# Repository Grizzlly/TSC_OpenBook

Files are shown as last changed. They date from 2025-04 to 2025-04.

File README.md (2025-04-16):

# OpenBook

An open source e-book reader based on ESP32.

## Block diagram

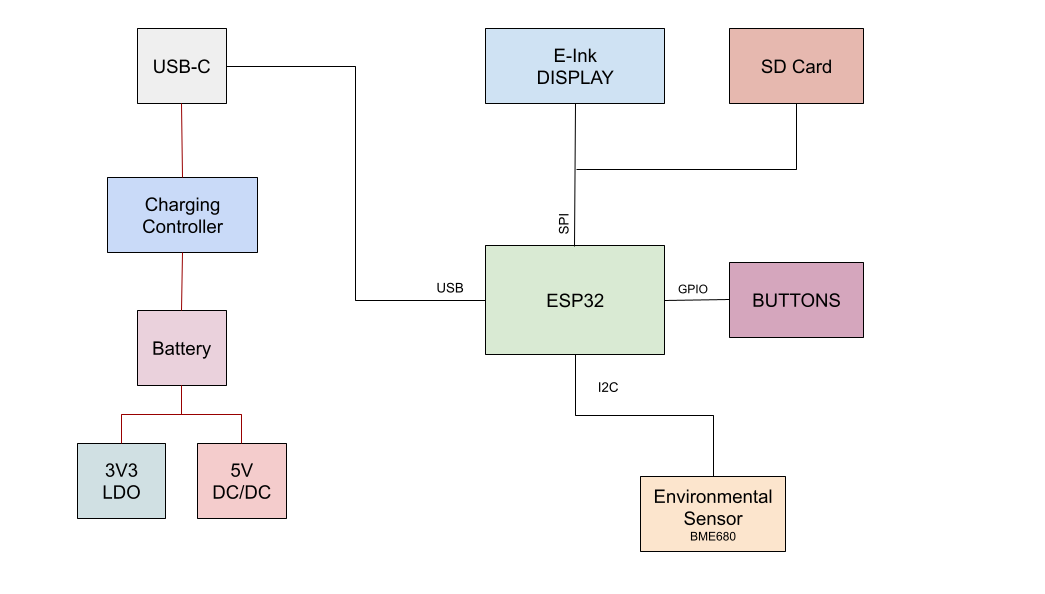
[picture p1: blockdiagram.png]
Block Diagram


## Hardware features

The main component of the device is the `ESP32` microcontroller, which is responsible for all the processing and control of the device. The `ESP32` is a powerful microcontroller with built-in Wi-Fi and Bluetooth capabilities, making it ideal for IoT applications.

Apart from the microcontroller, we have:

- `E-Paper Display`: connected via SPI interface.
- `SD Card`: connected via SPI interface.
- `USB-C charging and protection`: connected to the battery and the microcontroller. It also has electro static discharge protection.
- `Environmental sensors`: connected via I2C interface. These sensors measure temperature, humidity, and pressure.

## Power consumption

The `ESP32` microcontroller consumes `~250 mA` when
in use.
The display uses `~15 mA` when active.
The environmental sensors use `~3 mA` when active.

In total when active, the device consumes `~270 mA`. Given
that the battery has a capacity of `1800 mAh`,
we should expect a battery life of `~6.5 hours` of continuous use.

## Pin mapping for the ESP32

| Pin Name | Description | 
| --- | --- |
| EN | Reset |
| IO0 | Interrupt RTC |
| IO1 | Oscilator RTC |
| IO2 | SPI MISO |
| IO3 | Status display |
| IO4 | SD Card |
| IO5 | Data/Command |
| IO6 | SPI clock |
| IO7 | SPI data out |
| IO9 | Boot |
| IO10 | SPI E-Paper display command |
| IO11 | EPD |
| IO12 | Flash |
| IO13 | USB Data - |
| IO14 | USB Data + |
| IO15 | Navigation |
| IO16 | TX |
| IO17 | RX |
| IO18 | Reset DS3231 |
| IO19 | I2C Power |
| IO20 | EPD Power |
| IO21 | BME688 |
| IO22 | BME688 |
| IO23 | Reset display |

## BOM

| Piece Name | Quantity | Link |
| --- | --- | --- |
| ADAFRUIT_LEDCHIP-LED0603 | 1 | https://www.snapeda.com/parts/KP-1608SURCK/Kingbright/view-part/?ref=search&t=LED%200603 |
| C0402 | 1 | https://componentsearchengine.com/part-view/CC0402MRX5R5BB106/YAGEO |
| 112ATAARR03 | 1 | https://www.snapeda.com/parts/112A-TAAR-R03/Attend/view-part/ |
| 744043680 | 1 | https://eu.mouser.com/ProductDetail/Wurth-Elektronik/744043680?qs=PGXP4M47uW6VkZq%252BkzjrHA%3D%3D |
| BD5229G-TR | 1 | https://www.snapeda.com/parts/BD5229G-TR/Rohm/view-part/?ref=search&t=BD5229G-TR |
| CPH3225A | 1 | https://www.snapeda.com/parts/CPH3225A/Seiko/view-part/ |
| BUTTON_CUSYOMV1 | 3 | https://www.snapeda.com/search/?q=EVQP7L01P&search-type=parts |
| DS3231SN | 1 | https://www.snapeda.com/parts/DS3231SN%23/Analog%20Devices/view-part/?ref=search&t=DS3231SN%23 |
| ESP32 | 1 | https://www.snapeda.com/parts/ESP32-C6-WROOM-1-N8/Espressif%20Systems/view-part/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 |
| VARISTOR | 1 | https://ro.mouser.com/ProductDetail/EPCOS-TDK/B72520T0350K062?qs=dEfas%2FXlABIszF52uu7vrg%3D%3D |
| SD0805S020S1R0 | 1 | https://componentsearchengine.com/part-view/SD0805S020S1R0/Kyocera%20AVX |
| BME680 | 1 | https://www.snapeda.com/parts/BME680/Bosch%20Sensortec/view-part/?ref=search&t=bme680 |
| R0402 | 1 | https://componentsearchengine.com/part-view/R0402%201%25%20100%20K%20(RC0402FR-07100KL)/YAGEO |
| MOSFET | 1 | https://componentsearchengine.com/part-view/DMG2305UX-7/Diodes%20Incorporated |
| MCP73831 | 1 | https://componentsearchengine.com/part-view/MCP73831T-2ACI%2FOT/Microchip |
| SRJ | 1 | https://componentsearchengine.com/part-view/FH34SRJ-24S-0.5SH(99)/Hirose |
| MBR0530 | 1 | https://www.snapeda.com/parts/MBR0530/Onsemi/view-part/ |
| PGB1010603MR | 1 | https://www.snapeda.com/parts/PGB1010603MR/Littelfuse/view-part/ |
| QWIIC_CONNECTOR | 1 | https://www.snapeda.com/parts/PRT-14417/SparkFun/view-part/ |
| RCL_CPOL-EU | 1 | https://grabcad.com/library/tantalum-smd-capacitor-type-b-3528-1 |
| SAMACSYS_PARTS_USB4110-GF-A | 1 | https://www.snapeda.com/parts/USB4110-GF-A./Global%20Connector%20Technology/view-part/ |
| SI1308EDL-T1-GE3 | 1 | https://www.snapeda.com/parts/SI1308EDL-T1-GE3/Vishay/view-part/ |
| USBLC6-2SC6Y | 1 | https://www.snapeda.com/parts/USBLC6-2SC6Y/STMicroelectronics/view-part/?ref=dk&t=USBLC6-2SC6Y&con_ref=None |
| W25Q512JVEIQ | 1 | https://www.snapeda.com/parts/W25Q512JVEIQ/Winbond%20Electronics/view-part/?ref=search&t=W25Q512JVEIQ |
| XC6220A331MR-G | 1 | https://ro.mouser.com/ProductDetail/Torex-Semiconductor/XC6220A331MR-G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 |

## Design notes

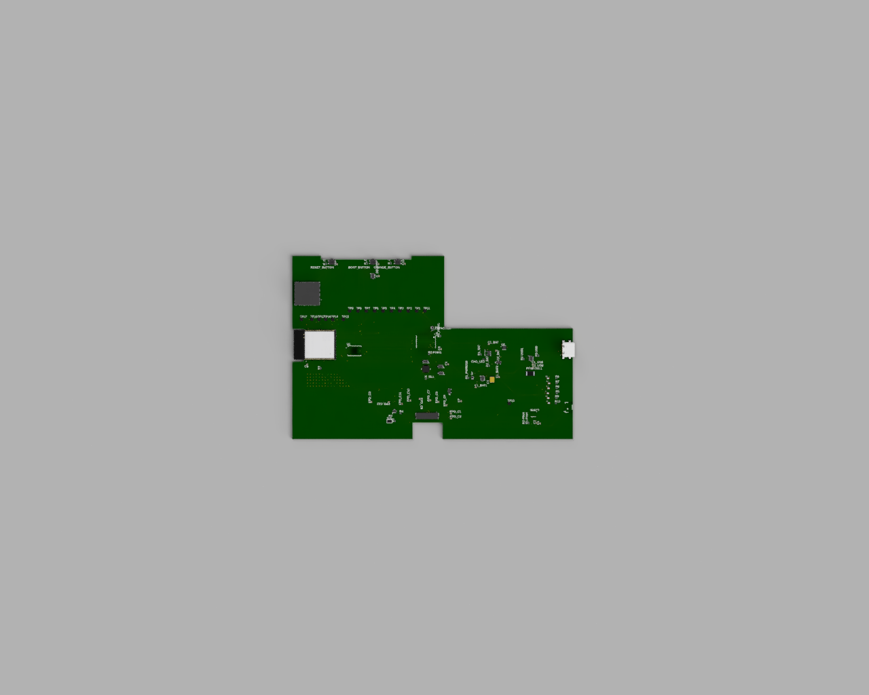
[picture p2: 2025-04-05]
Images/pcb_top.png

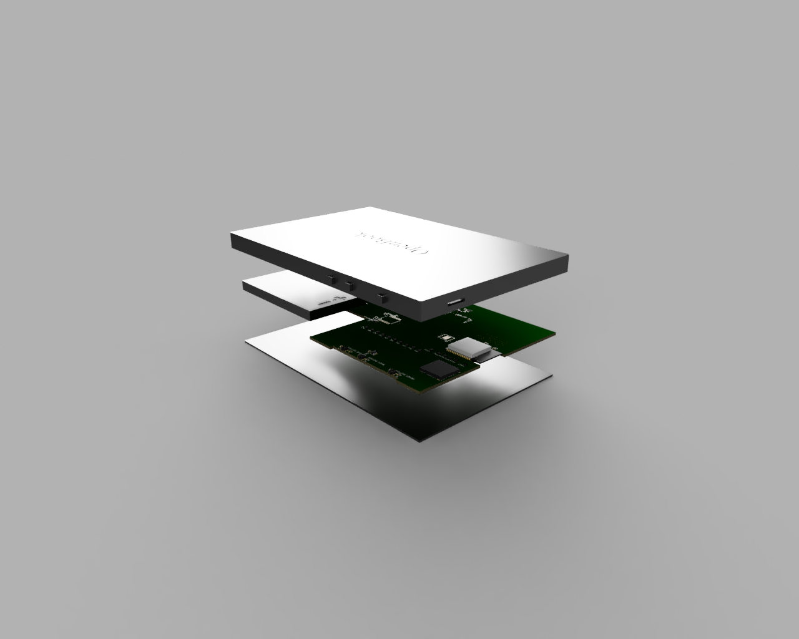
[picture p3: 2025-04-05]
Images/exploded_render.png

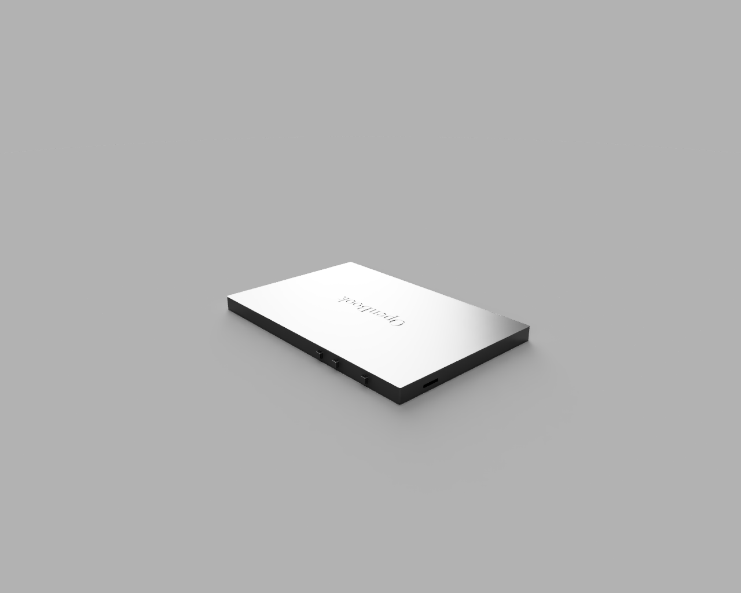
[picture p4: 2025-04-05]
Images/full_render.png

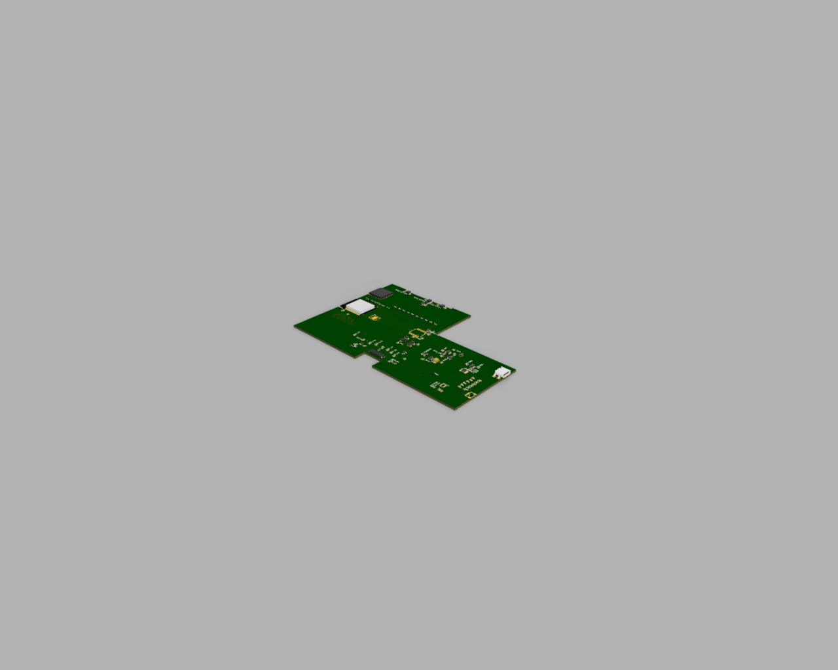
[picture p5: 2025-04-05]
Images/pcb.png

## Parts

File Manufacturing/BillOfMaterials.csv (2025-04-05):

Qty | Value | Device | Package | Parts | Description | ARROW_PART_NUMBER | ARROW_PRICE-STOCK | AVAILABILITY | CENTROID_NOT_SPECIFIED | CHECK_PRICES | COPYRIGHT | DATASHEET | DESCRIPTION | DIGIKEY_DESCRIPTION | DIGIKEY_PART_NUMBER | HEIGHT | LEAD_FREE | MANUFACTURER_NAME | MANUFACTURER_PART_NUMBER | MF | MFR_NAME | MOUSER_PART_NUMBER | MOUSER_PRICE-STOCK | MOUSER_TESTING_PART_NUMBER | MOUSER_TESTING_PRICE-STOCK | MP | MPN | PACKAGE | POPULARITY | PREFIX | PRICE | PROD_ID | PURCHASE-URL | ROHS | SNAPEDA_LINK | SPICEMODEL | SPICEPREFIX | TEMPERATURE_RANGE_HIGH | TEMPERATURE_RANGE_LOW | TP_SIGNAL_NAME | VALUE
1 |  | ADAFRUIT_LEDCHIP-LED0603 | ADAFRUIT_CHIP-LED0603 | CHG_LED | LED
1 |  | ESP32_WROVER_EAGLE-LTSPICE_RR0402 | ESP32_WROVER_EAGLE-LTSPICE_R0402 | R3 | RESISTOR, European symbol |  |  |  |  |  |  |  |  |  |  |  |  |  |  |  |  |  |  |  |  |  |  |  |  |  |  |  |  |  |  | NONE | R
1 |  | SJ | SJ | SJ1 | SMD solder JUMPER |  |  |  |  |  |  |  |  |  |  |  |  |  |  |  |  |  |  |  |  |  |  |  | 3
1 | 100K | ESP32_WROVER_EAGLE-LTSPICE_RR0402 | ESP32_WROVER_EAGLE-LTSPICE_R0402 | R1_PWRUSB | RESISTOR, European symbol |  |  |  |  |  |  |  |  |  |  |  |  |  |  |  |  |  |  |  |  |  |  |  |  |  |  |  |  |  |  | NONE | R
8 | 100nF | ESP32_WROVER_EAGLE-LTSPICE_CC0402 | ESP32_WROVER_EAGLE-LTSPICE_C0402 | C1, C1_USB, C2, C6, C8, C9, C10, C_DELAY | CAPACITOR, European symbol |  |  |  |  |  |  |  |  |  |  |  |  |  |  |  |  |  |  |  |  |  |  |  |  |  |  |  |  |  |  | NONE | C
1 | 100uF | RCL_CPOL-EUCT3528 | RCL_CT3528 | C3 | POLARIZED CAPACITOR, European symbol |  |  |  |  |  |  |  |  |  |  |  |  |  |  |  |  |  |  |  |  |  |  |  | 0 |  |  |  |  |  |  |  | C
16 | 10K | ESP32_WROVER_EAGLE-LTSPICE_RR0402 | ESP32_WROVER_EAGLE-LTSPICE_R0402 | R1, R1-PINH, R1_PINH1, R2-PINH, R2-PINH1, R4, R5, R6, R7, R8, R9, R10, R_BOOT, R_CHANGE, R_CL1, R_RESET | RESISTOR, European symbol |  |  |  |  |  |  |  |  |  |  |  |  |  |  |  |  |  |  |  |  |  |  |  |  |  |  |  |  |  |  | NONE | R
1 | 10uF | ESP32_WROVER_EAGLE-LTSPICE_CC0402 | ESP32_WROVER_EAGLE-LTSPICE_C0402 | C7 | CAPACITOR, European symbol |  |  |  |  |  |  |  |  |  |  |  |  |  |  |  |  |  |  |  |  |  |  |  |  |  |  |  |  |  |  | NONE | C
1 | 112A-TAAR-R03_ATTEND | 112A-TAAR-R03_ATTEND | 112ATAARR03ATTEND | J4 | Micro SD Card Socket, Push-Push Type, Top Mount, SMT, H=1.83mm, 10u |  |  |  |  |  |  |  | Micro SD Card Socket | Push-Push Type | Top Mount | SMT | H=1.83mm | 10u |  |  | 1.9mm |  | ATTEND | 112A-TAAR-R03 ATTEND
1 | 15 | ESP32_WROVER_EAGLE-LTSPICE_RR0402 | ESP32_WROVER_EAGLE-LTSPICE_R0402 | R_CAPACITOR | RESISTOR, European symbol |  |  |  |  |  |  |  |  |  |  |  |  |  |  |  |  |  |  |  |  |  |  |  |  |  |  |  |  |  |  | NONE | R
1 | 1uF | ESP32_WROVER_EAGLE-LTSPICE_CC0402 | ESP32_WROVER_EAGLE-LTSPICE_C0402 | C5 | CAPACITOR, European symbol |  |  |  |  |  |  |  |  |  |  |  |  |  |  |  |  |  |  |  |  |  |  |  |  |  |  |  |  |  |  | NONE | C
10 | 1uF/50V | ESP32_WROVER_EAGLE-LTSPICE_CC0402 | ESP32_WROVER_EAGLE-LTSPICE_C0402 | EPD_C1, EPD_C2, EPD_C5, EPD_C6, EPD_C7, EPD_C8, EPD_C9, EPD_C10, EPD_C11, EPD_C12 | CAPACITOR, European symbol |  |  |  |  |  |  |  |  |  |  |  |  |  |  |  |  |  |  |  |  |  |  |  |  |  |  |  |  |  |  | NONE | C
1 | 2.2 | ESP32_WROVER_EAGLE-LTSPICE_RR0402 | ESP32_WROVER_EAGLE-LTSPICE_R0402 | R2 | RESISTOR, European symbol |  |  |  |  |  |  |  |  |  |  |  |  |  |  |  |  |  |  |  |  |  |  |  |  |  |  |  |  |  |  | NONE | R
1 | 200 | ESP32_WROVER_EAGLE-LTSPICE_RR0402 | ESP32_WROVER_EAGLE-LTSPICE_R0402 | R1_BAT | RESISTOR, European symbol |  |  |  |  |  |  |  |  |  |  |  |  |  |  |  |  |  |  |  |  |  |  |  |  |  |  |  |  |  |  | NONE | R
2 | 20V/4.2A/52mO/1.4W | ESP32_WROVER_SPARKFUN-DISCRETESEMI_MOSFET_PCH-DMG2305UX-7 | ESP32_WROVER_SPARKFUN-DISCRETESEMI_SOT23-3 | Q1, Q2 | P-channel MOSFETs |  |  |  |  |  |  |  |  |  |  |  |  |  |  |  |  |  |  |  |  |  |  |  |  |  |  | TRAN-14388 |  |  |  |  |  |  |  |  | 20V/4.2A/52mO/1.4W
1 | 2K | ESP32_WROVER_EAGLE-LTSPICE_RR0402 | ESP32_WROVER_EAGLE-LTSPICE_R0402 | R2_BAT | RESISTOR, European symbol |  |  |  |  |  |  |  |  |  |  |  |  |  |  |  |  |  |  |  |  |  |  |  |  |  |  |  |  |  |  | NONE | R
5 | 4.7uF | ESP32_WROVER_EAGLE-LTSPICE_CC0402 | ESP32_WROVER_EAGLE-LTSPICE_C0402 | C1_BAT, C1_BAT1, C1_BAT2, C2_BAT, C2_USB | CAPACITOR, European symbol |  |  |  |  |  |  |  |  |  |  |  |  |  |  |  |  |  |  |  |  |  |  |  |  |  |  |  |  |  |  | NONE | C
1 | 4.7uF/25V | ESP32_WROVER_EAGLE-LTSPICE_CC0402 | ESP32_WROVER_EAGLE-LTSPICE_C0402 | C4 | CAPACITOR, European symbol |  |  |  |  |  |  |  |  |  |  |  |  |  |  |  |  |  |  |  |  |  |  |  |  |  |  |  |  |  |  | NONE | C
2 | 5k1 | ESP32_WROVER_EAGLE-LTSPICE_RR0402 | ESP32_WROVER_EAGLE-LTSPICE_R0402 | R2-USB, R2-USB1 | RESISTOR, European symbol |  |  |  |  |  |  |  |  |  |  |  |  |  |  |  |  |  |  |  |  |  |  |  |  |  |  |  |  |  |  | NONE | R
1 | 68uH | 744043680IND_4828-WE-TPC_WRE | IND_4828-WE-TPC_WRE | L1 |  |  |  |  |  |  | Copyright (C) 2024 Ultra Librarian. All rights reserved. |  |  |  |  |  |  |  | 744043680 |  | Wurth Electronics
1 | BD5229G-TR | BD5229G-TR | SOT95P280X125-5N | IC1 | Voltage Detector with Adjustable Delay Time: CMOS processes are utilized to develop high precision, low current consumption CMOS reset ICs that allow arbitrary setting of the delay time. The extensive lineup includes both Nch Open Drain and CMOS output types in a wide range of detection voltages (from 2.3V to 6.0V, in 0.1V steps), enabling selection of the ideal solution based on customer requirements. In addition, the entire series is of course both lead-free and RoHS-compliant. |  |  |  |  |  |  |  | Voltage Detector with Adjustable Delay Time: CMOS processes are utilized to develop high precision | low current consumption CMOS reset ICs that allow arbitrary setting of the delay time. The extensive lineup includes both Nch Open Drain and CMOS output types in a wide range of detection voltages (from 2.3V to 6.0V | in 0.1V steps) | enabling selection of the ideal solution based on customer requirements. In addition | the entire series is of course both lead-free and RoHS-compliant. |  |  | 1.25mm |  | ROHM Semiconductor | BD5229G-TR |  |  | 755-BD5229G-TR | https://www.mouser.co.uk/ProductDetail/ROHM-Semiconductor/BD5229G-TR?qs=4kLU8WoGk0vvnhrrYwdszw%3D%3D
3 | BUTTON_CUSYOMV1 | BUTTON_CUSYOMV1 | MYBUTTON | BOOT_BUTTON, CHANGE_BUTTON, RESET_BUTTON
1 | DS3231SN# | DS3231SN# | SOIC127P1032X265-16N | U3 | Real Time Clock Serial 16-Pin SOIC W T/R Check availability |  |  | In Stock |  | https://www.snapeda.com/parts/DS3231SN%23/Analog+Devices/view-part/?ref=eda |  |  | Extremely Accurate I²C-Integrated RTC/TCXO/Crystal |  |  |  |  |  |  | Analog Devices |  |  |  |  |  | DS3231SN# |  | SOIC-16 Maxim |  |  | None |  | https://www.snapeda.com/api/url_track_click_mouser/?unipart_id=99048&manufacturer=Analog Devices&part_name=DS3231SN#&search_term=None |  | https://www.snapeda.com/parts/DS3231SN%23/Analog+Devices/view-part/?ref=snap
1 | ESP32-C6-WROOM-1-N8 | ESP32-C6-WROOM-1-N8 | XCVR_ESP32-C6-WROOM-1-N8 | U2 | Check availability |  |  | In Stock |  | https://www.snapeda.com/parts/ESP32-C6-WROOM-1-N8/Espressif+Systems/view-part/?ref=eda |  |  | Multiprotocol Modules ESP32-C6 module | Wi-Fi 6 in 2.4 GHz band | Bluetooth 5 | Zigbee 3.0 and Thread. ESP34-WROOM Compatible - ENGINEERING SAMPLE |  |  |  |  |  |  | Espressif Systems |  |  |  |  |  | ESP32-C6-WROOM-1-N8 |  | None |  |  | None |  |  |  | https://www.snapeda.com/parts/ESP32-C6-WROOM-1-N8/Espressif+Systems/view-part/?ref=snap
1 | ESP32C6_VARISTORCN1812 | ESP32C6_VARISTORCN1812 | ESP32C6_VARISTOR_CT/CN1812 | PFMF.050.1 | VARISTOR |  |  |  |  |  |  |  |  |  |  |  |  |  |  |  |  |  |  |  |  |  |  |  | 0
2 | ESP32_WROVER_AVX---SD0805S020S1R0_AVX_SD0805S020S1R0_0_0AVX_SD0805S020S1R0_0_0 | ESP32_WROVER_AVX---SD0805S020S1R0_AVX_SD0805S020S1R0_0_0AVX_SD0805S020S1R0_0_0 | ESP32_WROVER_AVX---SD0805S020S1R0_AVX_SD0805S020S1R0_0 | D2, D7 | Schottky Barrier Rectifier Diode |  |  |  | No |  |  | http://datasheets.avx.com/schottky.pdf |  | DIODE SCHOTTKY 20V 1A 0805 | 478-7800-1-ND |  | yes |  |  | AVX |  | 581-SD0805S020S1R0 |  |  |  |  |  | 0805 (2012 metric) |  | D |  |  |  | yes |  |  |  | +125°C | -55°C
1 | ESP32_WROVER_BME680_BME680 | ESP32_WROVER_BME680_BME680 | ESP32_WROVER_BME680_PSON80P300X300X100-8N | SENSOR2 | Integrated Environmental Unit |  |  | Unavailable |  |  |  |  | Integrated Environmental Unit |  |  |  |  |  |  | Bosch Sensortec |  |  |  |  |  | BME680 |  | LGA-8 Bosch Tools |  |  | None
1 | ESP32_WROVER_SPARKFUN-IC-POWER_MCP73831 | ESP32_WROVER_SPARKFUN-IC-POWER_MCP73831 | ESP32_WROVER_SPARKFUN-IC-POWER_SOT23-5 | MCP73831 | MCP73831T Li-Ion, Li-Pol Controller |  |  |  |  |  |  |  |  |  |  |  |  |  |  |  |  |  |  |  |  |  |  |  |  |  |  | IC-09995
1 | FH34SRJ-24S-0.5SH_99_ | FH34SRJ-24S-0.5SH_99_ | FH34SRJ24S05SH99 | J1 | (0.50mm) Surface Mount, Right Angle |  |  |  |  |  |  |  | 24 Position FFC | FPC Connector Contacts | (0.50mm) Surface Mount | Right Angle |  |  | 1.1mm |  | Hirose | FH34SRJ-24S-0.5SH(99) |  |  | 798-FH34SRJ24S05SH99 | https://www.mouser.co.uk/ProductDetail/Hirose-Connector/FH34SRJ-24S-0.5SH99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
1 | MAX17048G+T10 | MAX17048G+T10 | SON50P200X200X80-9N | U4 | Check availability |  |  | In Stock |  | https://www.snapeda.com/parts/MAX17048G+T10/Analog+Devices/view-part/?ref=eda |  |  | 3µA 1-Cell/2-Cell Fuel Gauge with ModelGauge |  |  |  |  |  |  | Analog Devices |  |  |  |  |  | MAX17048G+T10 |  | TDFN-8 Maxim |  |  | None |  | https://www.snapeda.com/api/url_track_click_mouser/?unipart_id=329239&manufacturer=Analog Devices&part_name=MAX17048G+T10&search_term=None |  | https://www.snapeda.com/parts/MAX17048G+T10/Analog+Devices/view-part/?ref=snap
3 | MBR0530 | MBR0530 | SOD3716X135N | D3, D4, D5 | ON SEMICONDUCTOR - MBR0530 - DIODE, SCHOTTKY, 0.5A, 30V, SOD-123 |  |  | In Stock |  | https://www.snapeda.com/parts/MBR0530/Onsemi/view-part/?ref=eda |  |  | Diode Schottky 30 V 500mA Surface Mount SOD-123 |  |  |  |  |  |  | ON Semiconductor |  |  |  |  |  | MBR0530 |  | SOD-123-2 ON Semiconductor |  |  | None |  | https://www.snapeda.com/api/url_track_click_mouser/?unipart_id=179458&manufacturer=ON Semiconductor&part_name=MBR0530&search_term=None |  | https://www.snapeda.com/parts/MBR0530/Onsemi/view-part/?ref=snap
6 | PGB1010603MR | PGB1010603MR | DIOC1608X36N | D6, D8, D9, D10, D11, D12 | Check availability |  |  | In Stock |  | https://www.snapeda.com/parts/PGB1010603MR/Littelfuse/view-part/?ref=eda |  |  | 150V (Typ) Clamp - Ipp Tvs Diode Surface Mount 0603 (1608 Metric) |  |  |  |  |  |  | Littelfuse Inc. |  |  |  |  |  | PGB1010603MR |  | 0603 Littelfuse Inc. |  |  | None |  | https://www.snapeda.com/api/url_track_click_mouser/?unipart_id=5659453&manufacturer=Littelfuse Inc.&part_name=PGB1010603MR&search_term=None |  | https://www.snapeda.com/parts/PGB1010603MR/Littelfuse/view-part/?ref=snap
1 | QWIIC_RIGHT_ANGLE | QWIIC_CONNECTORJS-1MM | JST04_1MM_RA | J3 | SparkFun I2C Standard Qwiic Connector |  |  |  |  |  |  |  |  |  |  |  |  |  |  |  |  |  |  |  |  |  |  |  |  |  |  | CONN-13694 |  |  |  |  |  |  |  |  | QWIIC_RIGHT_ANGLE
1 | SAMACSYS_PARTS_USB4110-GF-A | SAMACSYS_PARTS_USB4110-GF-A | SAMACSYS_PARTS_USB4110GFA | J2 | CONN USB 2.0 TYPE-C R/A SMT |  |  |  |  |  |  |  | CONN USB 2.0 TYPE-C R/A SMT |  |  | 3.26mm |  | GCT (GLOBAL CONNECTOR TECHNOLOGY) | USB4110-GF-A |  |  | 640-USB4110-GF-A | https://www.mouser.co.uk/ProductDetail/GCT/USB4110-GF-A?qs=KUoIvG%2F9IlYiZvIXQjyJeA%3D%3D
1 | SI1308EDL-T1-GE3 | SI1308EDL-T1-GE3 | SOT65P210X110-3N | Q3 | MOSFET N-Ch 30V 1.5A TrenchFET SC70 Vishay Si1308EDL-T1-GE3 N-channel MOSFET Transistor, 1.5 A, 30 V, 3-Pin SC-70 |  |  | In Stock |  | https://www.snapeda.com/parts/SI1308EDL-T1-GE3/Vishay+Siliconix/view-part/?ref=eda |  |  | Si1308EDL-T1-GE3 N-channel MOSFET Transistor | 1.5 A | 30 V | 3-Pin SC-70 | Siliconix / Vishay SI1308EDL-T1-GE3 |  |  |  |  |  |  | Vishay Siliconix |  |  |  |  |  | SI1308EDL-T1-GE3 |  | SOT-323 Vishay Semiconductor |  |  | None |  | https://www.snapeda.com/api/url_track_click_mouser/?unipart_id=274603&manufacturer=Vishay Siliconix&part_name=SI1308EDL-T1-GE3&search_term=None |  | https://www.snapeda.com/parts/SI1308EDL-T1-GE3/Vishay+Siliconix/view-part/?ref=snap
17 | TPTP20R | TPTP20R | TP20R | TP1, TP2, TP3, TP4, TP5, TP6, TP7, TP8, TP9, TP10, TP11, TP12, TP13, TP14, TP15, TP16, TP17 | Test pad |  |  |  |  |  |  |  |  |  |  |  |  |  |  |  |  |  |  |  |  |  |  |  | 2
1 | USBLC6-2SC6Y | USBLC6-2SC6Y | SOT95P280X145-6N | D1 | Low Cap. ESD Protection Auto SOT-23-6 STMicroelectronics USBLC6-2SC6Y, Dual Uni-Directional TVS Diode Array, 6-Pin SOT-23 |  |  | In Stock |  | https://www.snapeda.com/parts/USBLC6-2SC6Y/STMicroelectronics/view-part/?ref=eda |  |  | 17V Clamp 5A (8/20µs) Ipp Tvs Diode Surface Mount SOT-23-6 |  |  |  |  |  |  | STMicroelectronics |  |  |  |  |  | USBLC6-2SC6Y |  | SOT-23-6 STMicroelectronics |  |  | None |  |  |  | https://www.snapeda.com/parts/USBLC6-2SC6Y/STMicroelectronics/view-part/?ref=snap
1 | W25Q512JVEIQ | W25Q512JVEIQ | SON127P600X800X80-9N | U1 | Check availability |  |  | In Stock |  | https://www.snapeda.com/parts/W25Q512JVEIQ/Winbond+Electronics/view-part/?ref=eda |  |  | FLASH - NOR Memory IC 512Mb (64M x 8) SPI - Quad I/O 133 MHz 8-WSON (8x6) |  |  |  |  |  |  | Winbond Electronics |  |  |  |  |  | W25Q512JVEIQ |  | Package |  |  | None |  |  |  | https://www.snapeda.com/parts/W25Q512JVEIQ/Winbond+Electronics/view-part/?ref=snap
1 | XC6220A331MR-G | XC6220A331MR-G | SOT95P280X120-5N | IC4 | LDO Voltage Regulators |  |  |  |  |  |  |  | LDO Voltage Regulators |  |  | 1.2mm |  | Torex | XC6220A331MR-G |  |  | 865-XC6220A331MR-G | https://www.mouser.co.uk/ProductDetail/Torex-Semiconductor/XC6220A331MR-G?qs=AsjdqWjXhJ8ZSWznL1J0gg%3D%3D

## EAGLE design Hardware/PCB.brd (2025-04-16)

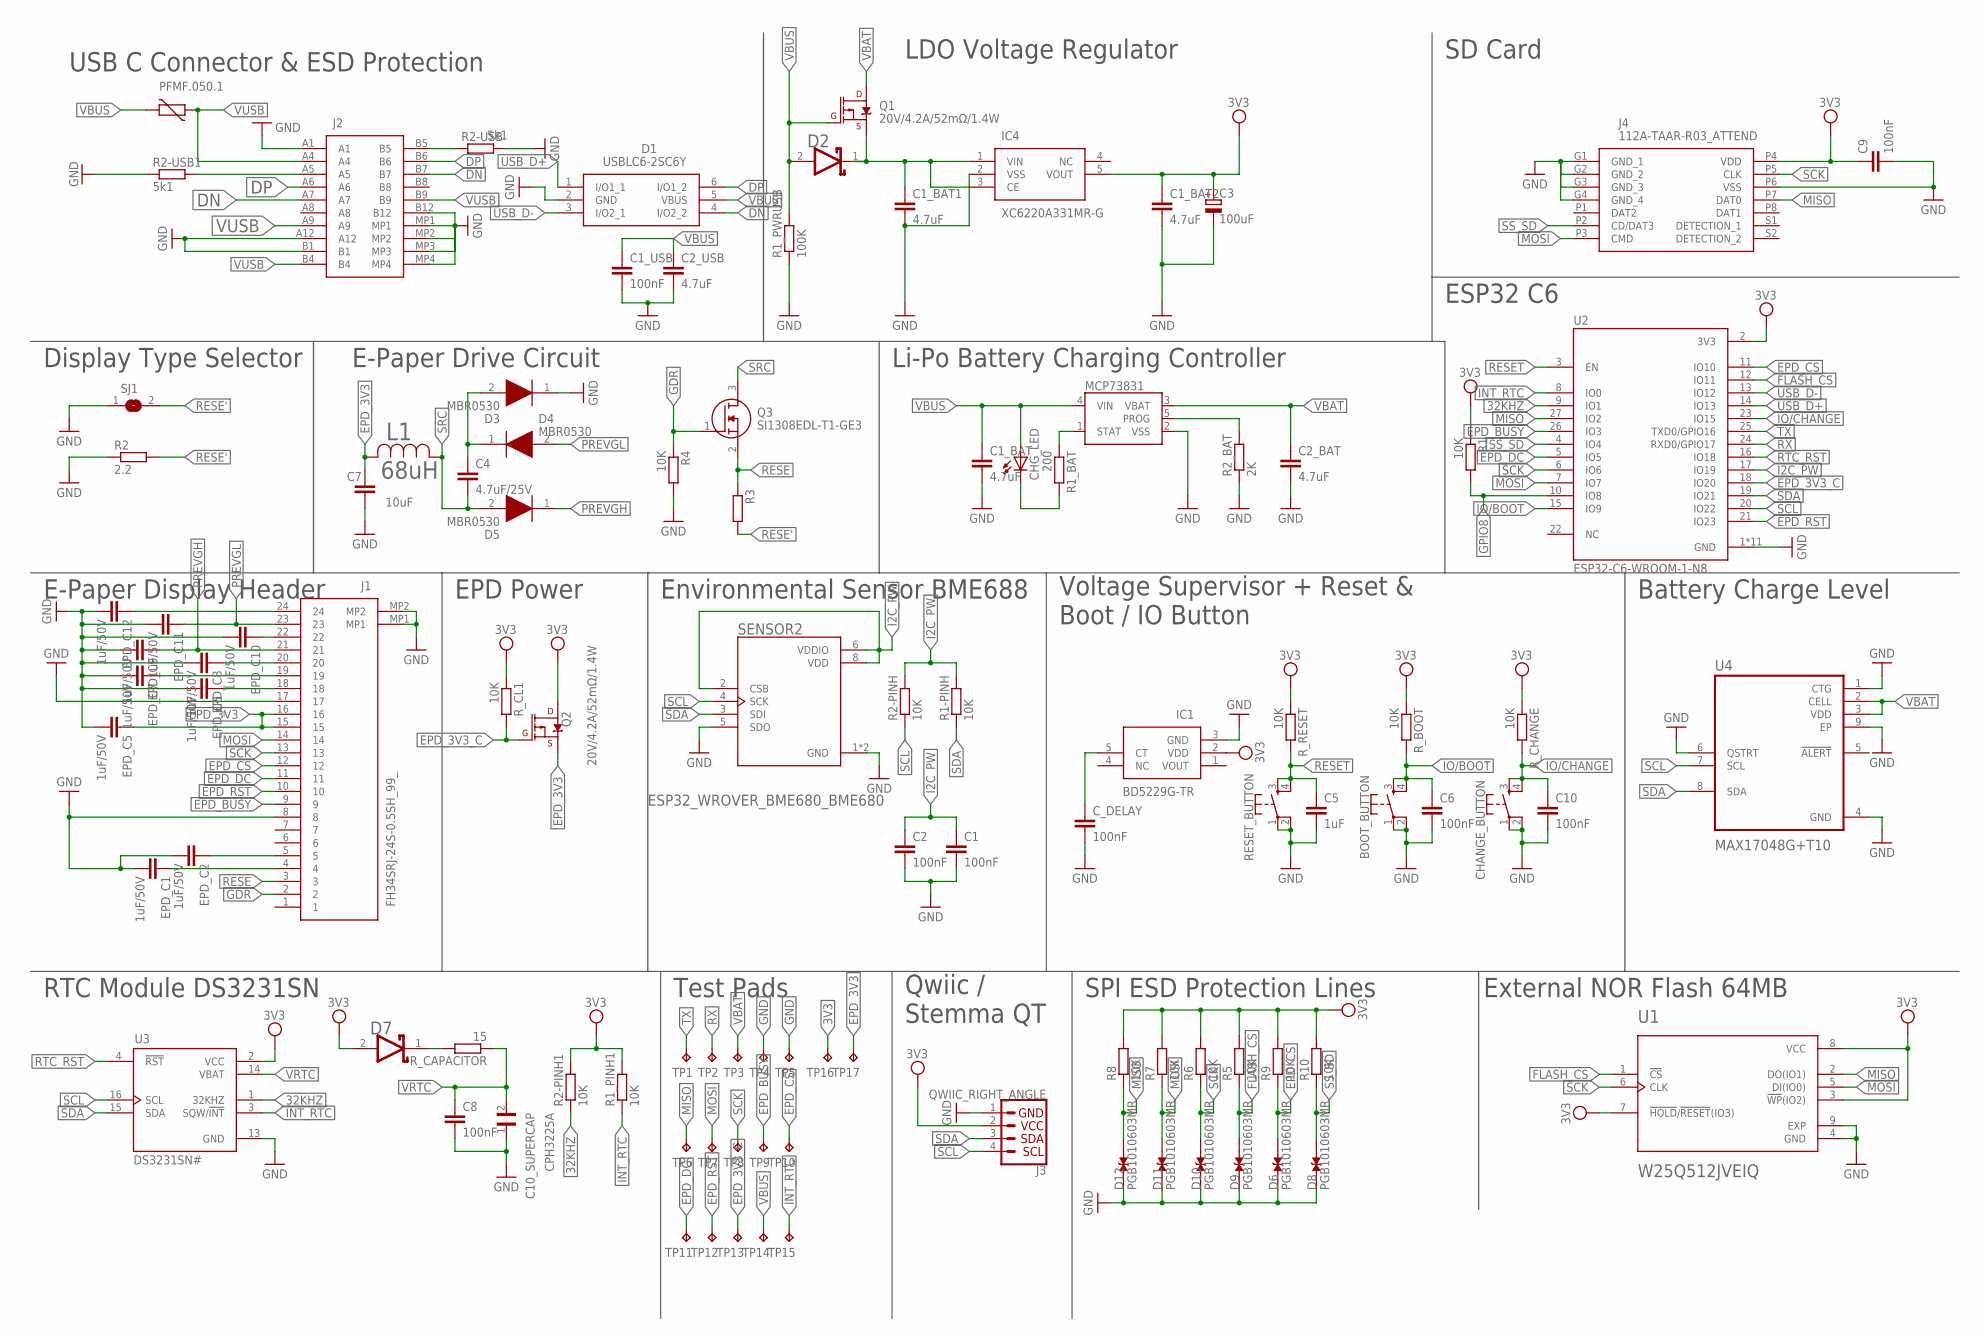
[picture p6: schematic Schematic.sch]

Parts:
BOOT_BUTTON: BUTTON_CUSYOMV1; MYBUTTON
C1, C1_USB, C2, C6, C8, C9, C10: 100nF; ESP32_WROVER_EAGLE-LTSPICE_C0402
C1_BAT, C1_BAT1, C1_BAT2, C2_BAT, C2_USB: 4.7uF; ESP32_WROVER_EAGLE-LTSPICE_C0402
C3: 100uF; RCL_CT3528
C4: 4.7uF/25V; ESP32_WROVER_EAGLE-LTSPICE_C0402
C5: 1uF; ESP32_WROVER_EAGLE-LTSPICE_C0402
C7: 10uF; ESP32_WROVER_EAGLE-LTSPICE_C0402
C10_SUPERCAP: CPH3225A; CAPCP3225X100N
CHANGE_BUTTON: BUTTON_CUSYOMV1; MYBUTTON
CHG_LED: ADAFRUIT_LEDCHIP-LED0603; ADAFRUIT_CHIP-LED0603
C_DELAY: 100nF; ESP32_WROVER_EAGLE-LTSPICE_C0402
D1: USBLC6-2SC6Y; SOT95P280X145-6N
D2, D7: ESP32_WROVER_AVX---SD0805S020S1R0_AVX_SD0805S020S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; ESP32_WROVER_AVX---SD0805S020S1R0_AVX_SD0805S020S1R0_0
D3, D4, D5: MBR0530; SOD3716X135N
D6, D8, D9, D10, D11, D12: PGB1010603MR; DIOC1608X36N
EPD_C1, EPD_C2, EPD_C5, EPD_C6, EPD_C7, EPD_C8, EPD_C9, EPD_C10, EPD_C11, EPD_C12: 1uF/50V; ESP32_WROVER_EAGLE-LTSPICE_C0402
IC1: BD5229G-TR; SOT95P280X125-5N
IC4: XC6220A331MR-G; SOT95P280X120-5N
J1: FH34SRJ-24S-0.5SH_99_; FH34SRJ24S05SH99
J2: SAMACSYS_PARTS_USB4110-GF-A; SAMACSYS_PARTS_USB4110GFA
J3: QWIIC_RIGHT_ANGLE; JST04_1MM_RA
J4: 112A-TAAR-R03_ATTEND; 112ATAARR03ATTEND
L1: 68uH; IND_4828-WE-TPC_WRE
MCP73831: ESP32_WROVER_SPARKFUN-IC-POWER_MCP73831; ESP32_WROVER_SPARKFUN-IC-POWER_SOT23-5
PFMF.050.1: ESP32C6_VARISTORCN1812; ESP32C6_VARISTOR_CT/CN1812
Q1, Q2: 20V/4.2A/52mΩ/1.4W; ESP32_WROVER_SPARKFUN-DISCRETESEMI_SOT23-3
Q3: SI1308EDL-T1-GE3; SOT65P210X110-3N
R1, R1-PINH, R1_PINH1, R2-PINH, R2-PINH1, R4, R5, R6, R7, R8, R9, R10: 10K; ESP32_WROVER_EAGLE-LTSPICE_R0402
R1_BAT: 200; ESP32_WROVER_EAGLE-LTSPICE_R0402
R1_PWRUSB: 100K; ESP32_WROVER_EAGLE-LTSPICE_R0402
R2: 2.2; ESP32_WROVER_EAGLE-LTSPICE_R0402
R2-USB, R2-USB1: 5k1; ESP32_WROVER_EAGLE-LTSPICE_R0402
R2_BAT: 2K; ESP32_WROVER_EAGLE-LTSPICE_R0402
R3: ESP32_WROVER_EAGLE-LTSPICE_RR0402; ESP32_WROVER_EAGLE-LTSPICE_R0402
RESET_BUTTON: BUTTON_CUSYOMV1; MYBUTTON
R_BOOT: 10K; ESP32_WROVER_EAGLE-LTSPICE_R0402
R_CAPACITOR: 15; ESP32_WROVER_EAGLE-LTSPICE_R0402
R_CHANGE: 10K; ESP32_WROVER_EAGLE-LTSPICE_R0402
R_CL1: 10K; ESP32_WROVER_EAGLE-LTSPICE_R0402
R_RESET: 10K; ESP32_WROVER_EAGLE-LTSPICE_R0402
SENSOR2: ESP32_WROVER_BME680_BME680; ESP32_WROVER_BME680_PSON80P300X300X100-8N
SJ1: SJ
TP1, TP2, TP3, TP4, TP5, TP6, TP7, TP8, TP9, TP10, TP11, TP12, TP13, TP14, TP15, TP16, TP17: TPTP20R; TP20R
U1: W25Q512JVEIQ; SON127P600X800X80-9N
U2: ESP32-C6-WROOM-1-N8; XCVR_ESP32-C6-WROOM-1-N8
U3: DS3231SN#; SOIC127P1032X265-16N
U4: MAX17048G+T10; SON50P200X200X80-9N

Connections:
3V3: C1_BAT2.1, C3.+, C9.1, D7.2 (ANODE), IC1.2 (VDD), IC4.5 (VOUT), J3.2, J4.P4 (VDD), Q2.3 (D), R1.1, R1_PINH1.2, R2-PINH1.2, R5.2, R6.2, R7.2, R8.2, R9.2, R10.2, R_BOOT.1, R_CHANGE.1, R_CL1.1, R_RESET.1, TP16.TP, U1.3 (!WP!(IO2)), U1.7 (!HOLD!/!RESET!(IO3)), U1.8 (VCC), U2.2 (3V3), U3.2 (VCC)
32KHZ: R2-PINH1.1, U2.9 (IO1), U3.1 (32KHZ)
DN: D1.4 (I/O2_2), J2.A7, J2.B7
DP: D1.6 (I/O1_2), J2.A6, J2.B6
EPD_3V3: C7.1, EPD_C5.1, J1.15, J1.16, L1.2, Q2.2 (S), TP17.TP
EPD_3V3_C: Q2.1 (G), R_CL1.2, TP13.TP, U2.18 (IO20)
EPD_BUSY: J1.9, TP9.TP, U2.26 (IO3)
EPD_CS: D6.2, J1.12, R9.1, TP10.TP, U2.11 (IO10)
EPD_DC: J1.11, TP11.TP, U2.5 (IO5)
EPD_RST: J1.10, TP12.TP, U2.21 (IO23)
FLASH_CS: D9.2, R5.1, U1.1 (!CS), U2.12 (IO11)
GDR: J1.2, Q3.1 (G), R4.1
GND: BOOT_BUTTON.1, BOOT_BUTTON.2, C1.2, C1_BAT.2, C1_BAT1.2, C1_BAT2.2, C1_USB.2, C2.2, C2_BAT.2, C2_USB.2, C3.-, C5.2, C6.2, C7.2, C8.2, C9.2, C10.2, C10_SUPERCAP.1, CHANGE_BUTTON.1, CHANGE_BUTTON.2, C_DELAY.2, D1.2 (GND), D3.1 (K), D6.1, D8.1, D9.1, D10.1, D11.1, D12.1, EPD_C1.2, EPD_C2.2, EPD_C5.2, EPD_C6.2, EPD_C7.2, EPD_C8.2, EPD_C9.2, EPD_C10.2, EPD_C11.2, EPD_C12.2, IC1.3 (GND), IC4.2 (VSS), J1.8, J1.17, J1.MP1, J1.MP2, J2.A1, J2.A12, J2.B1, J2.B12, J2.MP1, J2.MP2, J2.MP3, J2.MP4, J3.1, J4.G1 (GND_1), J4.G2 (GND_2), J4.G3 (GND_3), J4.G4 (GND_4), J4.P6 (VSS), MCP73831.2 (VSS), R1_PWRUSB.1, R2.1, R2-USB.2, R2-USB1.1, R2_BAT.1, R4.2, RESET_BUTTON.1, RESET_BUTTON.2, SENSOR2.1 (GND), SENSOR2.5 (SDO), SENSOR2.7 (GND), SJ1.1, TP4.TP, TP5.TP, U1.4 (GND), U1.9 (EXP), U2.1 (GND), U2.28 (GND), U2.29_1 (GND), U2.29_2 (GND), U2.29_3 (GND), U2.29_4 (GND), U2.29_5 (GND), U2.29_6 (GND), U2.29_7 (GND), U2.29_8 (GND), U2.29_9 (GND), U3.13 (GND), U4.1 (CTG), U4.4 (GND), U4.6 (QSTRT), U4.9 (EP)
GPIO8: R1.2, U2.10 (IO8)
I2C_PW: C1.1, C2.1, R1-PINH.2, R2-PINH.2, SENSOR2.2 (CSB), SENSOR2.6 (VDDIO), SENSOR2.8 (VDD), U2.17 (IO19)
INT_RTC: R1_PINH1.1, TP15.TP, U2.8 (IO0), U3.3 (SQW/!INT)
IO/BOOT: BOOT_BUTTON.3, BOOT_BUTTON.4, C6.1, R_BOOT.2, U2.15 (IO9)
IO/CHANGE: C10.1, CHANGE_BUTTON.3, CHANGE_BUTTON.4, R_CHANGE.2, U2.23 (IO15)
MISO: D12.2, J4.P7 (DAT0), R8.1, TP6.TP, U1.2 (DO(IO1)), U2.27 (IO2)
MOSI: D11.2, J1.14, J4.P3 (CMD), R7.1, TP7.TP, U1.5 (DI(IO0)), U2.7 (IO7)
unnamed: J2.A5, R2-USB1.2
unnamed: J2.B5, R2-USB.1
unnamed: C1_BAT1.1, D2.1 (CATHODE), IC4.1 (VIN), IC4.3 (CE), Q1.2 (S)
unnamed: C4.1, D3.2 (A), D4.1 (K)
unnamed: MCP73831.1 (STAT), R1_BAT.1
unnamed: CHG_LED.C, R1_BAT.2
unnamed: MCP73831.5 (PROG), R2_BAT.2
unnamed: EPD_C1.1, J1.4
unnamed: EPD_C2.1, J1.5
unnamed: EPD_C10.1, J1.22
unnamed: EPD_C8.1, J1.20
unnamed: EPD_C6.1, J1.18
unnamed: C_DELAY.1, IC1.5 (CT)
unnamed: EPD_C12.1, J1.24
unnamed: D7.1 (CATHODE), R_CAPACITOR.2
unnamed: EPD_C7.1, J1.19
PREVGH: D5.1 (K), EPD_C9.1, J1.21
PREVGL: D4.2 (A), EPD_C11.1, J1.23
RESE: J1.3, Q3.2 (S), R3.1
RESE': R2.2, R3.2, SJ1.2
RESET: C5.1, RESET_BUTTON.3, RESET_BUTTON.4, R_RESET.2, U2.3 (EN)
RTC_RST: U2.16 (IO18), U3.4 (!RST)
RX: TP2.TP, U2.24 (RXD0/GPIO17)
SCK: D10.2, J1.13, J4.P5 (CLK), R6.1, TP8.TP, U1.6 (CLK), U2.6 (IO6)
SCL: J3.4, R2-PINH.1, SENSOR2.4 (SCK), U2.20 (IO22), U3.16 (SCL), U4.7 (SCL)
SDA: J3.3, R1-PINH.1, SENSOR2.3 (SDI), U2.19 (IO21), U3.15 (SDA), U4.8 (SDA)
SRC: C4.2, D5.2 (A), L1.1, Q3.3 (D)
SS_SD: D8.2, J4.P2 (CD/DAT3), R10.1, U2.4 (IO4)
TX: TP1.TP, U2.25 (TXD0/GPIO16)
USB_D+: D1.1 (I/O1_1), U2.14 (IO13)
USB_D-: D1.3 (I/O2_1), U2.13 (IO12)
VBAT: C2_BAT.1, MCP73831.3 (VBAT), Q1.3 (D), TP3.TP, U4.2 (CELL), U4.3 (VDD)
VBUS: C1_BAT.1, C1_USB.1, C2_USB.1, CHG_LED.A, D1.5 (VBUS), D2.2 (ANODE), MCP73831.4 (VIN), PFMF.050.1.2, Q1.1 (G), R1_PWRUSB.2, TP14.TP
VRTC: C8.1, C10_SUPERCAP.2, R_CAPACITOR.1, U3.14 (VBAT)
VUSB: J2.A4, J2.A9, J2.B4, J2.B9, PFMF.050.1.1

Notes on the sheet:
USB C Connector & ESD Protection
LDO Voltage Regulator
SD Card
Display Type Selector
E-Paper Drive Circuit
Li-Po Battery Charging Controller
ESP32 C6
E-Paper Display Header
EPD Power
Environmental Sensor BME688
Voltage Supervisor + Reset & Boot / IO Button
Battery Charge Level
RTC Module DS3231SN
Test Pads
Qwiic / Stemma QT
SPI ESD Protection Lines
External NOR Flash 64MB

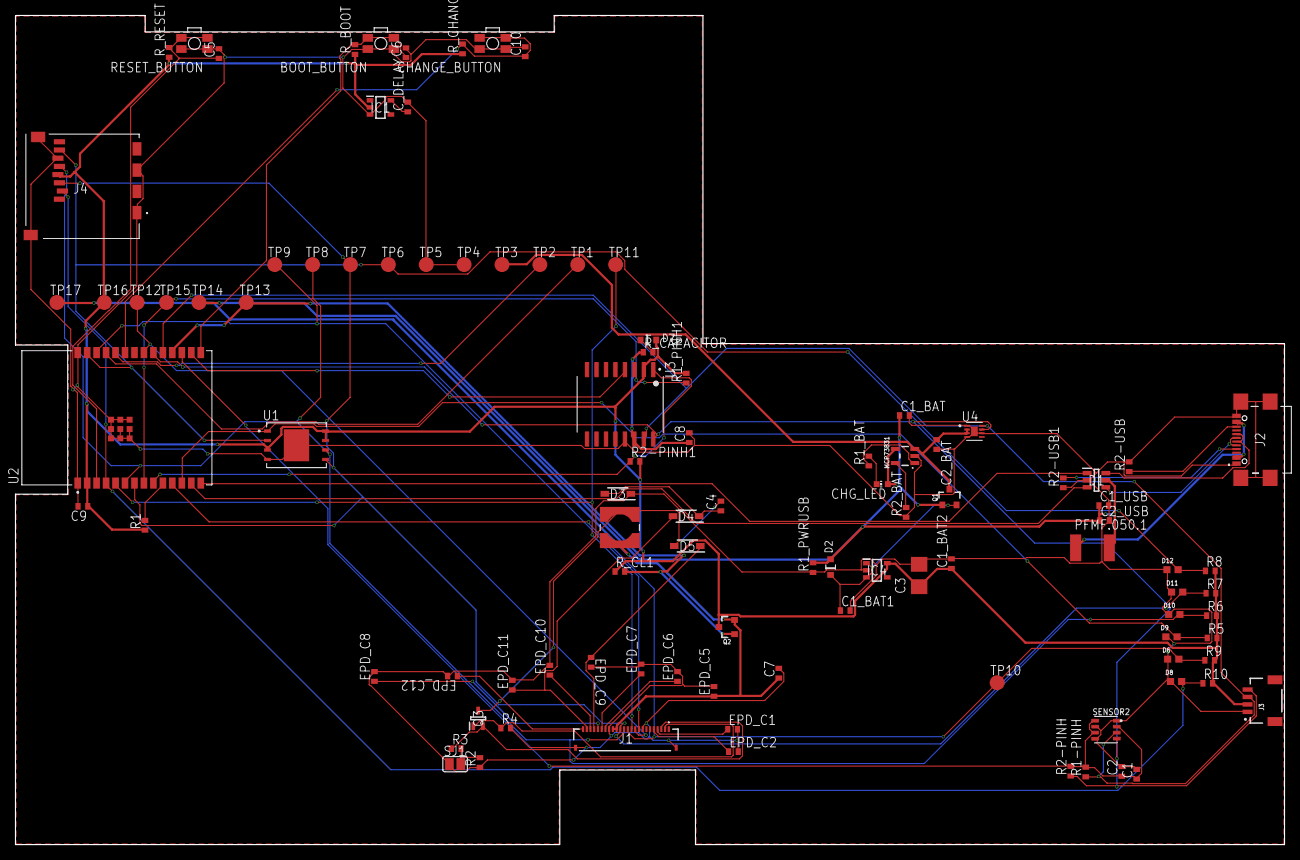
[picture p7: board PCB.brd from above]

Board: 2 copper layers, 170.2 x 111.2 mm, 102 parts (0 on the bottom side), 55 nets.

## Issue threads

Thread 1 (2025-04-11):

Via in pad or too close to pad

reinuu1, 2025-04-11:
A via is placed very close to, or inside, a pad near the power trace labeled SRC. This is flagged by the DRC rule SMD-Via ( L1 )

Closed 2025-04-16.

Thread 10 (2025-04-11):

Incomplete README documentation

reinuu1, 2025-04-11:
The current README is missing a mandatory section as per project requirements.  It includes partial hardware functionality, the block diagram, and a Bill of Materials, but there is no pin mapping explanation for the ESP32-C6.

Closed 2025-04-16.

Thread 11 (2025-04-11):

Missing visible PCB dimensions on layout

reinuu1, 2025-04-11:
Great job on respecting all the mechanical dimensions — it's clear that everything fits nicely and follows the expected constraints. However, the actual PCB outline dimensions (length, width, key placements) are not visible in the layout view.

Recommendation:
Add visible dimension annotations

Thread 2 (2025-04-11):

Missing stitching vias in GND polygon pour

reinuu1, 2025-04-11:
There are large areas on the PCB with empty space inside the GND polygon pour, especially around the central region and lower side of the board.

Grizzlly, 2025-04-11:
I am not sure if I understand the issue. I do have via stitching near the ESP32 module, as per project requirements.

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

Closed 2025-04-16.

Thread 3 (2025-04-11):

Incomplete README documentation

reinuu1, 2025-04-11:
The current README is missing a mandatory section as per project requirements.  It includes partial hardware functionality, the block diagram, and a Bill of Materials, but there is no pin mapping explanation for the _ESP32-C6_.

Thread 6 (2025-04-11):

Unspecified resistor value (R3)

reinuu1, 2025-04-11:
Resistor R3 is missing a defined value in the schematic.

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

Closed 2025-04-16.

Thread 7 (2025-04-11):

Improper multi-pin connection on GND lines (single-node join) - SD CARD

reinuu1, 2025-04-11:
In the SD CARD section of the schematic, all four GND pins (G1–G4) are connected using a single horizontal line touching only one pin, with no visible junction dots on the others.

G2–G4 are not actually connected to ground.

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

Closed 2025-04-16.

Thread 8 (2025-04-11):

Improper multi-pin connection on GND lines - USB C connector & ESD protection

reinuu1, 2025-04-11:
In the USB C connector & ESD protection section of the schematic, all four GND pins (MP1–MP4) are connected using a single horizontal line touching only one pin, with no visible junction dots on the others.

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

Closed 2025-04-16.

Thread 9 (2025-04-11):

Unnecessary library/instance text shown on schematic

reinuu1, 2025-04-11:
The schematic includes an unused and unclear text string: ESP32_WROVER_BME680_BME680 near the environmental sensor (BME688) block.

Closed 2025-04-16.

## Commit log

2025-03-26 Added schematic.
    [Schematic.sch]
2025-04-05 Added PCB.
    [PCB.brd]
2025-04-05 Added gerbers.
2025-04-05 Added BOM.
    [BillOfMaterials.csv]
2025-04-05 Added PNP.
    [PickAndPlace.csv]
2025-04-05 Added full device 3D model.
2025-04-05 Added 3D exploded view of device.
2025-04-05 README for device.
2025-04-16 Added pin mapping explanation for ESP32.
2025-04-16 Fixed PCB design.
    Fixed overlapping errors with L1 and via.
    [PCB.brd]
2025-04-16 Schematic fixes.
    Fixed some junctions not being properly connected.
    Added missing component values.
    [Schematic.sch]

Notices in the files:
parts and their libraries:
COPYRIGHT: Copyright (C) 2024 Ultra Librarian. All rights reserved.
